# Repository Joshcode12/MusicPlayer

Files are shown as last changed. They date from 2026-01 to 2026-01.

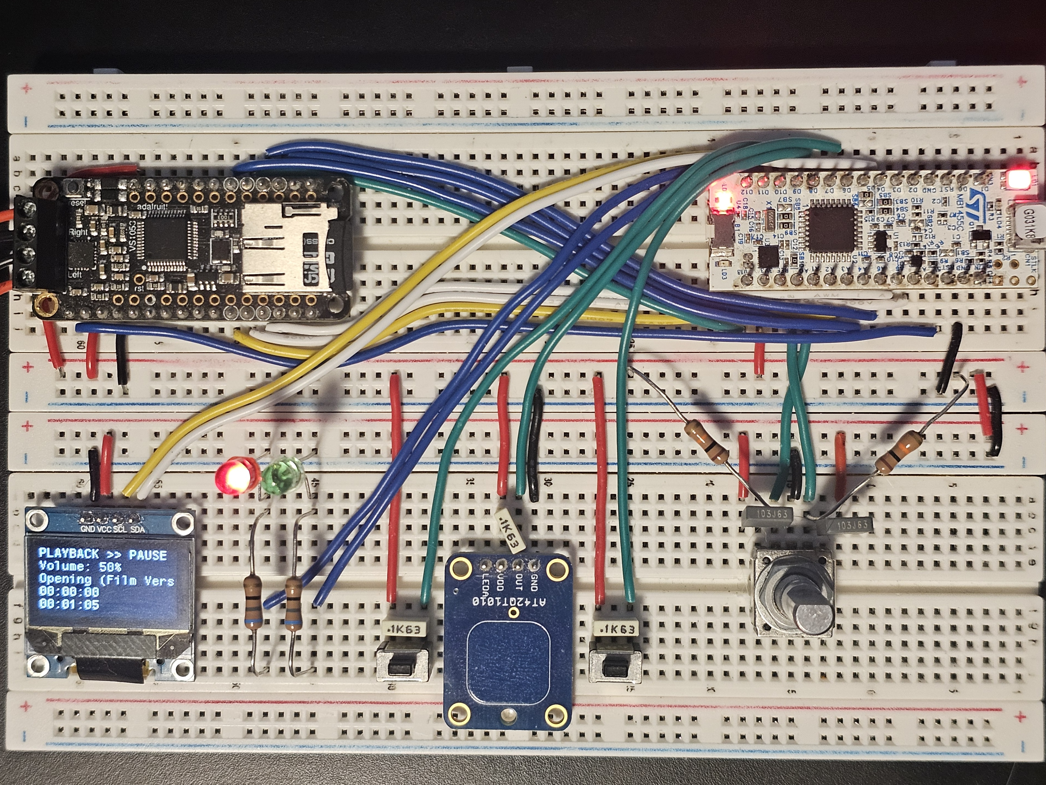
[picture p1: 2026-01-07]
Extra/Breadboard.jpg

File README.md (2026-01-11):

* * * * *

STM32 Music Player
==================




A standalone MP3 player built around the STM32G031K8 microcontroller, featuring SD card storage, OLED display, rotary encoder control, and a VS1053b hardware audio decoder. Designed to run on extremely limited Flash/RAM while remaining responsive and fully non‐blocking.

* * * * *

**Current Version:** v1.0.0 (First Release)

Hardware Components
-------------------

- **MCU**: STM32G031K8 (NUCLEO‐G031K8 board)
- **Audio Decoder**: VS1053b (MP3/AAC/WMA/MIDI hardware decoder)
- **Display**: SSD1306 128×64 OLED (I²C)
- **Storage**: SD Card (SPI, 3‑wire mode)
- **Controls**:
    - Rotary encoder (navigation + volume)
    - 3 push buttons (Play, Next, Previous)
    - Hardware debouncing via RC filters
- **Indicators**:
    - 2 PWM‑controlled LEDs (Play/Pause status)

* * * * *

Features
--------
- MP3 playback via VS1053b
- SD card access using lightweight SPI driver
- OLED UI with playback state and metadata
- Rotary encoder for navigation and volume
- Play / Pause / Next / Previous buttons
- Non‐blocking state machine
- Automatic ID3 tag extraction (title, duration)
- Simple numeric track system (`001.mp3`, `002.mp3`, ...)

* * * * *

SD Card Layout
--------------

Playback is intentionally **non‐recursive** for speed and RAM efficiency.

```
/audio/
    001.mp3
    002.mp3
    003.mp3
```

* * * * *

Pin Configuration
-----------------

### SPI1 --- Audio & SD Card
- PA5 --- SPI1_SCK
- PA6 --- SPI1_MISO
- PA7 --- SPI1_MOSI
- PA4 --- SD_CS
- PA11 --- MP3_CS
- PA12 --- XD_CS
- PB3 --- DREQ (VS1053b Data Request)

### I2C1 --- OLED Display
- PA9 --- I2C1_SCL (400 kHz)
- PA10 --- I2C1_SDA

### TIM2 --- Rotary Encoder
- PA0 --- TIM2_CH1
- PA1 --- TIM2_CH2

### TIM3 --- PWM LEDs
- PB4 --- TIM3_CH1 (Pause LED)
- PB5 --- TIM3_CH2 (Play LED)

### Buttons
- PB0 --- Play/Pause
- PB8 --- Next
- PB9 --- Previous

### Other
- PC6 --- LD3 (Status LED)

* * * * *

Software Architecture
---------------------

### Initialization Order
1. `HAL_Init()`
2. `SystemClock_Config()` --- 64 MHz (HSI + PLL)
3. `MX_GPIO_Init()` --- all CS pins HIGH
4. `MX_DMA_Init()`
5. `MX_SPI1_Init()` --- 2 Mbps
6. `MX_I2C1_Init()` --- 400 kHz
7. `MX_TIM2_Init()` --- encoder mode
8. `MX_TIM3_Init()` --- PWM LEDs
9. `MX_FATFS_Init()` --- filesystem

### DMA Channels
- DMA1_CH4 --- I2C1_TX

### Libraries
- **HAL** --- STM32 HAL
- **FatFS** --- R0.12c
- **SD Card SPI driver** --- kiwih/cubeide-sd-card
- **SSD1306 OLED** --- afiskon/stm32-ssd1306

* * * * *

Playback Architecture
---------------------

### Event Queue
- Lock‐free SPSC ring buffer
- Used for button and encoder events
- Extremely lightweight (8‑entry queue)

### State Machine
- **Playback State**
- **Error State**
- Fully non‐blocking (no `HAL_Delay()` inside states except when needed to show user info before it is updated)

### ID3 Tag Extraction
- Reads ID3v2 tags when loading a track
- Extracts:
    - Title
    - Duration
- Requires only a small buffer of 64 bytes

### File Naming
- Firmware generates filenames:
  ```
  audio/%03d.mp3
  ```
- No directory scanning required, but was done to avoid wrapping around
- Perfect for low‑RAM systems

* * * * *

Development Phases
------------------

### Phase 1 --- Hardware Bring‐Up
- [x] GPIO + PWM LED test
- [x] Button input
- [x] Rotary encoder reading

### Phase 2 --- Peripherals
- [x] SSD1306 display
- [x] SD card SPI driver
- [x] FatFS mounting

### Phase 3 --- Audio
- [X] VS1053b SPI communication
- [X] MP3 streaming from SD card

### Phase 4 --- Integration
- [X] Playback controls
- [X] Volume control via encoder
- [X] Track metadata display (Title and duration)
- [X] Volume storage

* * * * *

Building and Flashing
---------------------

### Build (CMake)

```
mkdir build && cd build
cmake ..
make
```

### Flash (st-flash)

```
st-flash write build/MusicPlayerFirmware.bin 0x8000000
```

### Flash (STM32CubeProgrammer)

Use ST‑Link to flash the `.elf` file.

* * * * *

Pictures
--------
Breadboard image

Cubemx pin-out

License
-------

MIT

Author
------

Joshua E

Acknowledgments
---------------
-   STMicroelectronics --- HAL/LL drivers
-   VLSI Solution --- VS1053b documentation
-   Aleksander Alekseev --- SSD1306 library
-   Hammond Pearce --- SD card SPI driver

* * * * *

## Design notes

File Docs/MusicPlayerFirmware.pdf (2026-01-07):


07/01/2026

MusicPlayerFirmware Project Configuration Report

## 1. Description

### 1.1. Project

Project Name | MusicPlayerFirmware
Board Name | NUCLEO-G031K8
Generated with: | STM32CubeMX 6.16.1
Date | 01/07/2026

### 1.2. MCU

MCU Series | STM32G0
MCU Line | STM32G0x1
MCU name | STM32G031K8Tx
MCU Package | LQFP32
MCU Pin number | 32

### 1.3. Core(s) information

Core(s) | ARM Cortex-M0+

## 2. Pinout Configuration

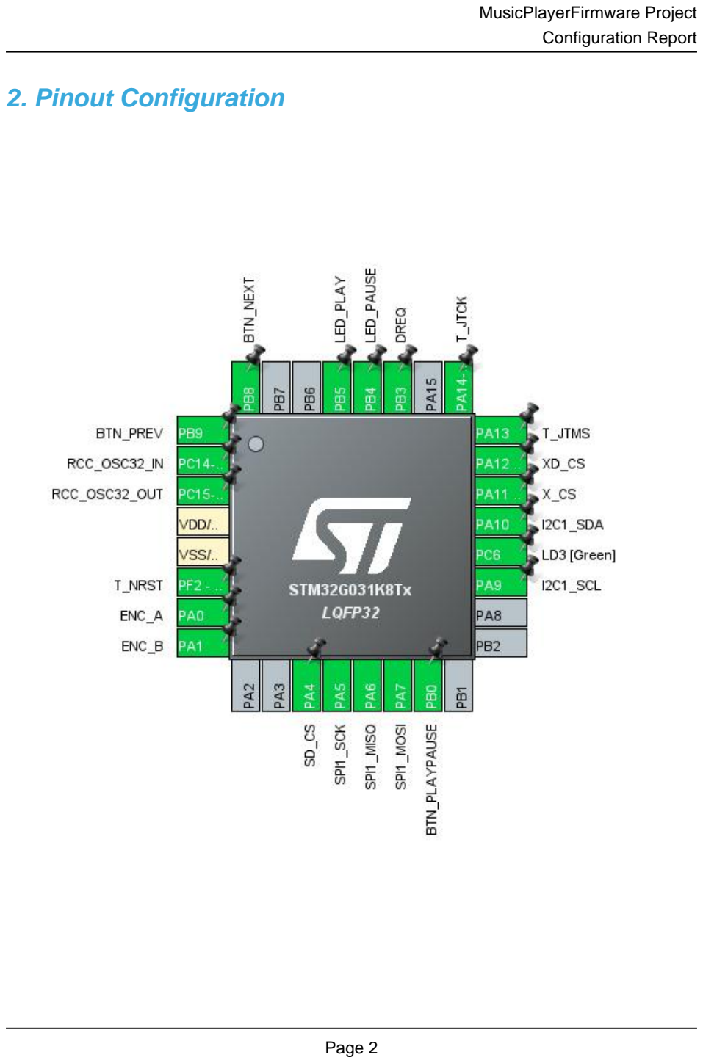
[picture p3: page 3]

## 3. Pins Configuration

Pin Number LQFP32 | Pin Name (function after reset) | Pin Type | Alternate Function(s) | Label
1 | PB9 | I/O | GPIO_EXTI9 | BTN_PREV
2 | PC14-OSC32_IN (PC14) | I/O | RCC_OSC32_IN
3 | PC15-OSC32_OUT (PC15) | I/O | RCC_OSC32_OUT
4 | VDD/VDDA | Power
5 | VSS/VSSA | Power
6 | PF2 - NRST | I/O | GPIO_EXTI2 | T_NRST
7 | PA0 | I/O | TIM2_CH1 | ENC_A
8 | PA1 | I/O | TIM2_CH2 | ENC_B
11 | PA4 * | I/O | GPIO_Output | SD_CS
12 | PA5 | I/O | SPI1_SCK | SPI1_SCK
13 | PA6 | I/O | SPI1_MISO | SPI1_MISO
14 | PA7 | I/O | SPI1_MOSI | SPI1_MOSI
15 | PB0 | I/O | GPIO_EXTI0 | BTN_PLAYPAUSE
19 | PA9 | I/O | I2C1_SCL
20 | PC6 * | I/O | GPIO_Output | LD3 [Green]
21 | PA10 | I/O | I2C1_SDA
22 | PA11 [PA9] * | I/O | GPIO_Output | X_CS
23 | PA12 [PA10] * | I/O | GPIO_Output | XD_CS
24 | PA13 | I/O | SYS_SWDIO | T_JTMS
25 | PA14-BOOT0 | I/O | SYS_SWCLK | T_JTCK
27 | PB3 * | I/O | GPIO_Input | DREQ
28 | PB4 | I/O | TIM3_CH1 | LED_PAUSE
29 | PB5 | I/O | TIM3_CH2 | LED_PLAY
32 | PB8 | I/O | GPIO_EXTI8 | BTN_NEXT

* The pin is affected with an I/O function

## 4. Clock Tree Configuration

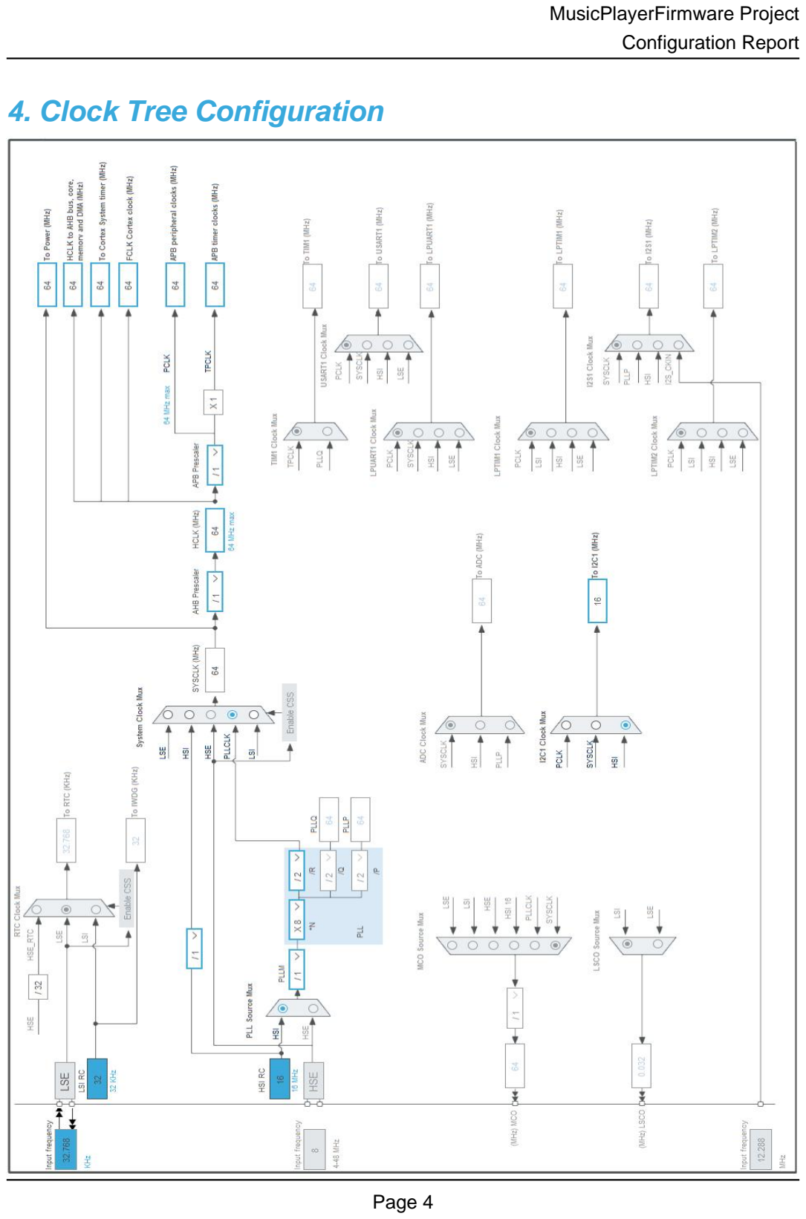
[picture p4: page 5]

## 1. Power Consumption Calculator report

### 1.1. Microcontroller Selection

Series | STM32G0
Line | STM32G0x1
MCU | STM32G031K8Tx
Datasheet | DS12992_Rev0

### 1.2. Parameter Selection

Temperature | 25
Vdd | 3.0

### 1.3. Battery Selection

Battery | Li-SOCL2(AAA700)
Capacity | 700.0 mAh
Self Discharge | 0.08 %/month
Nominal Voltage | 3.6 V
Max Cont Current | 10.0 mA
Max Pulse Current | 30.0 mA
Cells in series | 1
Cells in parallel | 1

### 1.4. Sequence

Step | Step1 | Step2
Mode | RUN | STOP1
Vdd | 3.0 | 3.0
Voltage Source | Battery | Battery
Range | Range1-High | Range1-High
Fetch Type | FLASH | Flash-PowerDown
CPU Frequency | 64 MHz | 16 MHz
Clock Configuration | HSI PLL | HSI
Clock Source Frequency | 16 MHz | 16 MHz
Peripherals
Additional Cons. | 0 mA | 0 mA
Average Current | 5.25 mA | 3.36 µA
Duration | 0.1 ms | 0.9 ms
DMIPS | 80.0 | 0.0
Ta Max | 128.8 | 130
Category | In DS Table | In DS Table

### 1.5. Results

Sequence Time | 1 ms | Average Current | 528.02 µA
Battery Life | 1 month, 24 days, 17 hours | Average DMIPS | 80.0 DMIPS

### 1.6. Chart

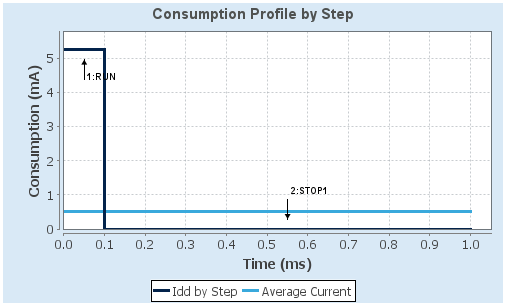
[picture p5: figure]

## 2. Software Project

### 2.1. Project Settings

Name | Value
Project Name | MusicPlayerFirmware
Project Folder | C:\Users\joshs\PersonalProjects\EmbeddedProjects\MusicPlayer\MusicPlayerFir
Toolchain / IDE | CMake
Firmware Package Name and Version | STM32Cube FW_G0 V1.6.2
Application Structure | Advanced
Generate Under Root | No
Do not generate the main() | No
Minimum Heap Size | 0x200
Minimum Stack Size | 0x400

### 2.2. Code Generation Settings

Name | Value
STM32Cube MCU packages and embedded software | Copy only the necessary library files
Generate peripheral initialization as a pair of '.c/.h' files | Yes
Backup previously generated files when re-generating | No
Keep User Code when re-generating | Yes
Delete previously generated files when not re-generated | Yes
Set all free pins as analog (to optimize the power consumption) | Yes
Enable Full Assert | No

### 2.3. Advanced Settings - Generated Function Calls

Rank | Function Name | Peripheral Instance Name
1 | SystemClock_Config | RCC
2 | MX_GPIO_Init | GPIO
3 | MX_DMA_Init | DMA
4 | MX_I2C1_Init | I2C1
5 | MX_SPI1_Init | SPI1
6 | MX_TIM3_Init | TIM3
7 | MX_TIM2_Init | TIM2
8 | MX_FATFS_Init | FATFS

## 3. Peripherals and Middlewares Configuration

### 3.1. I2C1

I2C: I2C
3.1.1. Parameter Settings:

Timing configuration:

Custom Timing | Disabled
I2C Speed Mode | Fast Mode *
I2C Speed Frequency (KHz) | 400
Rise Time (ns) | 100
Fall Time (ns) | 100
Coefficient of Digital Filter | 0
Analog Filter | Enabled
Timing | 0x00300617 *
Slave Features:
Clock No Stretch Mode | Disabled
General Call Address Detection | Disabled
Primary Address Length selection | 7-bit
Dual Address Acknowledged | Disabled
Primary slave address | 60 *

### 3.2. RCC

Low Speed Clock (LSE) : Crystal/Ceramic Resonator
3.2.1. Parameter Settings:

System Parameters:

VDD voltage (V) | 3.3
Instruction Cache | Enabled
Prefetch Buffer | Enabled
Data Cache | Enabled
Flash Latency(WS) | 2 WS (3 CPU cycle)
RCC Parameters:
HSI Calibration Value | 64
HSE Startup Timout Value (ms) | 100
LSE Startup Timout Value (ms) | 5000
Power Parameters:
Power Regulator Voltage Scale | Power Regulator Voltage Scale 1

Peripherals Clock Configuration:

Generate the peripherals clock configuration | TRUE

### 3.3. SPI1

Mode: Full-Duplex Master
3.3.1. Parameter Settings:

Basic Parameters:

Frame Format | Motorola
Data Size | 8 Bits
First Bit | MSB First
Clock Parameters:
Prescaler (for Baud Rate) | 8 *
Baud Rate | 8.0 MBits/s *
Clock Polarity (CPOL) | Low
Clock Phase (CPHA) | 1 Edge
Advanced Parameters:
CRC Calculation | Disabled
NSSP Mode | Enabled
NSS Signal Type | Software

### 3.4. SYS

mode: Debug
Timebase Source: SysTick

### 3.5. TIM2

Combined Channels: Encoder Mode
3.5.1. Parameter Settings:

Counter Settings:

Prescaler (PSC - 16 bits value) | 0
Counter Mode | Up
Counter Period (AutoReload Register - 32 bits value ) | 4294967295
Internal Clock Division (CKD) | No Division
auto-reload preload | Disable
Trigger Output (TRGO) Parameters:

Master/Slave Mode (MSM bit) | Disable (Trigger input effect not delayed)
Trigger Event Selection TRGO | Reset (UG bit from TIMx_EGR)
Encoder:
Encoder Mode | Encoder Mode TI1 and TI2 *

____ Parameters for Channel 1 ____
Polarity | Falling Edge *
IC Selection | Direct
Prescaler Division Ratio | No division
Input Filter | 0
____ Parameters for Channel 2 ____
Polarity | Falling Edge *
IC Selection | Direct
Prescaler Division Ratio | No division
Input Filter | 0

### 3.6. TIM3

Channel1: PWM Generation CH1 Channel2: PWM Generation CH2
3.6.1. Parameter Settings:

Counter Settings:

Prescaler (PSC - 16 bits value) | 63 *
Counter Mode | Up
Counter Period (AutoReload Register - 16 bits value ) | 999 *
Internal Clock Division (CKD) | No Division
auto-reload preload | Enable *
Trigger Output (TRGO) Parameters:
Master/Slave Mode (MSM bit) | Disable (Trigger input effect not delayed)
Trigger Event Selection TRGO | Reset (UG bit from TIMx_EGR)
Clear Input:
Clear Input Source | Disable
PWM Generation Channel 1:
Mode | PWM mode 1
Pulse (16 bits value) | 250 *
Output compare preload | Enable
Fast Mode | Disable
CH Polarity | High
PWM Generation Channel 2:

Mode | PWM mode 1
Pulse (16 bits value) | 250 *
Output compare preload | Enable
Fast Mode | Disable
CH Polarity | High

### 3.7. FATFS

mode: User-defined
3.7.1. Set Defines:

Version:

FATFS version | R0.12c
Function Parameters:
FS_READONLY (Read-only mode) | Disabled
FS_MINIMIZE (Minimization level) | Enabled with 6 functions removed *
USE_STRFUNC (String functions) | Disabled *
USE_FIND (Find functions) | Disabled
USE_MKFS (Make filesystem function) | Disabled *
USE_FASTSEEK (Fast seek function) | Disabled *
USE_EXPAND (Use f_expand function) | Disabled
USE_CHMOD (Change attributes function) | Disabled
USE_LABEL (Volume label functions) | Disabled
USE_FORWARD (Forward function) | Disabled
Locale and Namespace Parameters:
CODE_PAGE (Code page on target) | Latin 1
USE_LFN (Use Long Filename) | Disabled
MAX_LFN (Max Long Filename) | 255
LFN_UNICODE (Enable Unicode) | ANSI/OEM
STRF_ENCODE (Character encoding) | ANSI/OEM *
FS_RPATH (Relative Path) | Disabled
Physical Drive Parameters:
VOLUMES (Logical drives) | 1
MAX_SS (Maximum Sector Size) | 512
MIN_SS (Minimum Sector Size) | 512
MULTI_PARTITION (Volume partitions feature) | Disabled
USE_TRIM (Erase feature) | Disabled
FS_NOFSINFO (Force full FAT scan) | 0
System Parameters:

FS_TINY (Tiny mode)

| Enabled *
FS_EXFAT (Support of exFAT file system) | Disabled
FS_NORTC (Timestamp feature) | Fixed timestamp *
NORTC_YEAR (Year for timestamp) | 2026 *
NORTC_MON (Month for timestamp) | 1 *
NORTC_MDAY (Day for timestamp) | 1 *
FS_REENTRANT (Re-Entrancy) | Disabled
FS_TIMEOUT (Timeout ticks) | 1000
FS_LOCK (Number of files opened simultaneously) | 1 *

* User modified value

## 4. System Configuration

### 4.1. GPIO configuration

IP | Pin | Signal | GPIO mode | GPIO pull/up pull down | Max Speed | User Label
I2C1 | PA9 | I2C1_SCL | Alternate Function Open Drain | Pull-up * | Low
| PA10 | I2C1_SDA | Alternate Function Open Drain | Pull-up * | Low
RCC | PC14-OSC32_IN (PC14) | RCC_OSC32_IN | n/a | n/a | n/a
| PC15-OSC32_OU T (PC15) | RCC_OSC32_O UT | n/a | n/a | n/a
SPI1 | PA5 | SPI1_SCK | Alternate Function Push Pull | No pull-up and no pull-down | Low | SPI1_SCK
| PA6 | SPI1_MISO | Alternate Function Push Pull | Pull-up * | Low | SPI1_MISO
| PA7 | SPI1_MOSI | Alternate Function Push Pull | Pull-up * | Low | SPI1_MOSI
SYS | PA13 | SYS_SWDIO | n/a | n/a | n/a | T_JTMS
| PA14-BOOT0 | SYS_SWCLK | n/a | n/a | n/a | T_JTCK
TIM2 | PA0 | TIM2_CH1 | Alternate Function Push Pull | No pull-up and no pull-down | Low | ENC_A
| PA1 | TIM2_CH2 | Alternate Function Push Pull | No pull-up and no pull-down | Low | ENC_B
TIM3 | PB4 | TIM3_CH1 | Alternate Function Push Pull | No pull-up and no pull-down | Low | LED_PAUSE
| PB5 | TIM3_CH2 | Alternate Function Push Pull | No pull-up and no pull-down | Low | LED_PLAY
GPIO | PB9 | GPIO_EXTI9 | External Interrupt Mode with Rising edge trigger detection | Pull-down * | n/a | BTN_PREV
| PF2 - NRST | GPIO_EXTI2 | External Interrupt Mode with Rising edge trigger detection | No pull-up and no pull-down | n/a | T_NRST
| PA4 | GPIO_Output | Output Push Pull | Pull-up * | Low | SD_CS
| PB0 | GPIO_EXTI0 | External Interrupt Mode with Rising edge trigger detection | Pull-down * | n/a | BTN_PLAYPAUSE
| PC6 | GPIO_Output | Output Push Pull | No pull-up and no pull-down | Low | LD3 [Green]
| PA11 [PA9] | GPIO_Output | Output Push Pull | Pull-up * | Low | X_CS
| PA12 [PA10] | GPIO_Output | Output Push Pull | Pull-up * | Low | XD_CS
| PB3 | GPIO_Input | Input mode | Pull-down * | n/a | DREQ
| PB8 | GPIO_EXTI8 | External Interrupt Mode with Rising edge trigger detection | Pull-down * | n/a | BTN_NEXT

### 4.2. DMA configuration

DMA request | Stream | Direction | Priority
I2C1_TX | DMA1_Channel1 | Memory To Peripheral | Medium *

I2C1_TX: DMA1_Channel1 DMA request Settings:

Mode: | Normal
Peripheral Increment: | Disable
Memory Increment: | Enable *
Peripheral Data Width: | Byte
Memory Data Width: | Byte

### 4.3. NVIC configuration

4.3.1. NVIC
Interrupt Table | Enable | Preenmption Priority | SubPriority
Non maskable interrupt | true | 0 | 0
Hard fault interrupt | true | 0 | 0
System service call via SWI instruction | true | 0 | 0
Pendable request for system service | true | 0 | 0
System tick timer | true | 0 | 0
EXTI line 0 and line 1 interrupts | true | 0 | 0
EXTI line 2 and line 3 interrupts | true | 0 | 0
EXTI line 4 to 15 interrupts | true | 0 | 0
DMA1 channel 1 interrupt | true | 0 | 0
I2C1 event global interrupt / I2C1 wake-up interrupt through EXTI line 23 | true | 0 | 0
SPI1 global interrupt | true | 0 | 0
PVD interrupt through EXTI line 16 | unused
Flash global interrupt | unused
RCC global interrupt | unused
TIM2 global interrupt | unused
TIM3 global interrupt | unused
4.3.2. NVIC Code generation
Enabled interrupt Table | Select for init sequence ordering | Generate IRQ handler | Call HAL handler
Non maskable interrupt | false | true | false
Hard fault interrupt | false | true | false
System service call via SWI instruction | false | true | false
Pendable request for system service | false | true | false
System tick timer | false | true | true
EXTI line 0 and line 1 interrupts | false | true | true
EXTI line 2 and line 3 interrupts | false | true | true
EXTI line 4 to 15 interrupts | false | true | true
DMA1 channel 1 interrupt | false | true | true
I2C1 event global interrupt / I2C1 wake-up interrupt through EXTI line 23 | false | true | true
SPI1 global interrupt | false | true | true

* User modified value

## 5. System Views

5.1. Category view
5.1.1. Current

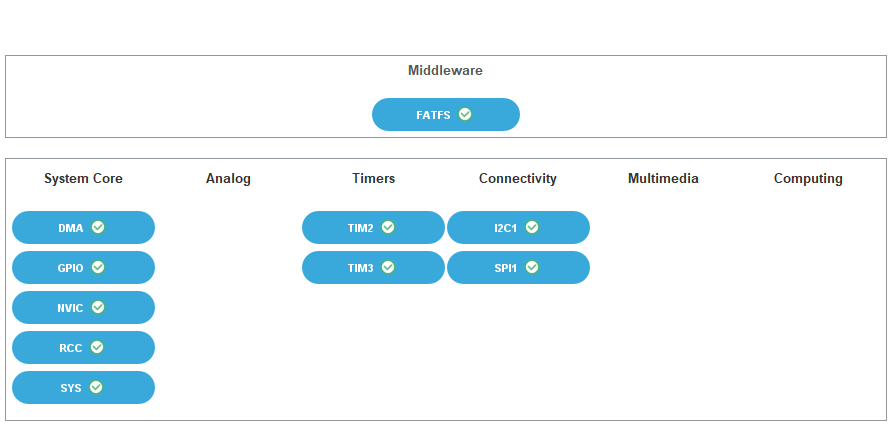
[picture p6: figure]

## 6. Docs & Resources

Type | Link
IBIS models | https://www.st.com/resource/en/ibis_model/stm32g0_ibis.zip
System View Description | https://www.st.com/resource/en/svd/stm32g0-svd.zip
Presentations | https://www.st.com/resource/en/product_presentation/stm32-stm8_embedded_software_solutions.pdf
Presentations | https://www.st.com/resource/en/product_presentation/stm32_eval-tools_portfolio.pdf
Presentations | https://www.st.com/resource/en/product_presentation/stm32_stm8_functi onal-safety-packages.pdf
Presentations | https://www.st.com/resource/en/product_presentation/stm32g0_marketing_pres.pdf
Presentations | https://www.st.com/resource/en/product_presentation/stm32-usb-c-pd-solutions-presentation.pdf
Presentations | https://www.st.com/resource/en/product_presentation/stm32-stm8_software_development_tools.pdf
Presentations | https://www.st.com/resource/en/product_presentation/microcontrollers-stm32-family-overview.pdf
Presentations | https://www.st.com/resource/en/product_presentation/microcontrollers-stm32-entry-level-graphics.pdf
Brochures | https://www.st.com/resource/en/brochure/products-and-solutions-for-plcs-and-smart-i-os.pdf
Brochures | https://www.st.com/resource/en/brochure/expansion-boards-for-intelligent-power-switches.pdf
Flyers | https://www.st.com/resource/en/flyer/flstm32g0.pdf
Flyers | https://www.st.com/resource/en/flyer/flstm32nucleo.pdf
Flyers | https://www.st.com/resource/en/flyer/flstm32trust.pdf
Flyers | https://www.st.com/resource/en/flyer/fldpstpfc11120.pdf
Security Bulletin | https://www.st.com/resource/en/technical_note/tn1489-security-bulletin- tn1489stpsirt-physical-attacks-on-stm32-and-stm32cube-firmware-

| stmicroelectronics.pdf
Application Notes | https://www.st.com/resource/en/application_note/an1709-emc-design-guide-for-stm8-stm32-and-legacy-mcus-stmicroelectronics.pdf
Application Notes | https://www.st.com/resource/en/application_note/an3126-audio-and-waveform-generation-using-the-dac-in-stm32-products-stmicroelectronics.pdf
Application Notes | https://www.st.com/resource/en/application_note/an3155-usart-protocol-used-in-the-stm32-bootloader-stmicroelectronics.pdf
Application Notes | https://www.st.com/resource/en/application_note/an3156-usb-dfu-protocol-used-in-the-stm32-bootloader-stmicroelectronics.pdf
Application Notes | https://www.st.com/resource/en/application_note/an4221-i2c-protocol-used-in-the-stm32-bootloader-stmicroelectronics.pdf
Application Notes | https://www.st.com/resource/en/application_note/an4286-spi-protocol-used-in-the-stm32-bootloader-stmicroelectronics.pdf
Application Notes | https://www.st.com/resource/en/application_note/an4655-virtually-increasing-the-number-of-serial-communication-peripherals-in-stm32-applications-stmicroelectronics.p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
Application Notes | https://www.st.com/resource/en/application_note/an4750-handling-of-soft-errors-in-stm32-applications-stmicroelectronics.pdf
Application Notes | https://www.st.com/resource/en/application_note/an4776-generalpurpose-timer-cookbook-for-stm32-microcontrollers-stmicroelectronics.pdf
Application Notes | https://www.st.com/resource/en/application_note/an4803-highspeed-si-simulations-using-ibis-and-boardlevel-simulations-using-hyperlynx-si-on-stm32-mcus-and-mpus-stmic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
Application Notes | https://www.st.com/resource/en/application_note/an4989-stm32-microcontroller-debug-toolbox-stmicroelectronics.pdf
Application Notes | https://www.st.com/resource/en/application_note/an5027-interfacing-pdm-digital-microphones-using-stm32-mcus-and-mpus-stmicroelectronics.pdf
Application Notes | https://www.st.com/resource/en/application_note/an5096-getting-started-with-stm32g0-series-hardware-development-stmicroelectronics.pdf
Application Notes | https://www.st.com/resource/en/application_note/an5110-stm32cube-firmware-examples-for-stm32g0-series-stmicroelectronics.pdf
Application Notes | https://www.st.com/resource/en/application_note/an5145-migration-of-

| applications-from-stm32f0-series-to-stm32g0-series--stmicroelectronics.pdf
Application Notes | https://www.st.com/resource/en/application_note/an4899-stm32-microcontroller-gpio-hardware-settings-and-lowpower-consumption-stmicroelectronics.pdf
Application Notes | https://www.st.com/resource/en/application_note/an5612-esd-protection-of-stm32-mcus-and-mpus-stmicroelectronics.pdf
Application Notes | https://www.st.com/resource/en/application_note/an4991-how-to-wake-up-an-stm32-microcontroller-from-lowpower-mode-with-the-usart-or-the-lpuart-stmicroelectronics.pdf
Application Notes | https://www.st.com/resource/en/application_note/an4838-introduction-to-memory-protection-unit-management-on-stm32-mcus-stmicroelectronics.pdf
Application Notes | https://www.st.com/resource/en/application_note/an5225-introduction-to-usb-typec-power-delivery-for-stm32-mcus-and-mpus-stmicroelectronics.pdf
Application Notes | https://www.st.com/resource/en/application_note/an4777-how-to-optimize-power-consumption-on-stm32-mcus-stmicroelectronics.pdf
Application Notes | https://www.st.com/resource/en/application_note/an4894-how-to-use-eeprom-emulation-on-stm32-mcus-stmicroelectronics.pdf
Application Notes | https://www.st.com/resource/en/application_note/an5537-how-to-use-adc-oversampling-techniques-to-improve-signaltonoise-ratio-on-stm32-mcus-stmicroelectronics.pdf
Application Notes | https://www.st.com/resource/en/application_note/an5036-guidelines-for-thermal-management-on-stm32-applications-stmicroelectronics.pdf
Application Notes | https://www.st.com/resource/en/application_note/an5405-how-to-use-fdcan-bootloader-protocol-on-stm32-mcus-stmicroelectronics.pdf
Application Notes | https://www.st.com/resource/en/application_note/an5690-how-to-use-vrefbuf-peripheral-on-stm32-mcus-and-mpus-stmicroelectronics.pdf
Application Notes | https://www.st.com/resource/en/application_note/an4230-introduction-to-random-number-generation-validation-using-the-nist-statistical-test-suite-for-stm32-mcus-and-m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
Application Notes | https://www.st.com/resource/en/application_note/an2548-introduction-to-

| dma-controller-for-stm32-mcus-stmicroelectronics.pdf
Application Notes | https://www.st.com/resource/en/application_note/an4013-introduction-to-timers-for-stm32-mcus-stmicroelectronics.pdf
Application Notes | https://www.st.com/resource/en/application_note/an4277-how-to-use-pwm-shutdown-for-motor-control-and-digital-power-conversion-on-stm32-mcus-stmicroelectronics.pdf
Application Notes | https://www.st.com/resource/en/application_note/an4635-how-to-optimize-lpuart-power-consumption-on-stm32-mcus-stmicroelectronics.pdf
Application Notes | https://www.st.com/resource/en/application_note/an4759-introduction-to-using-the-hardware-realtime-clock-rtc-and-the-tamper-management-unit-tamp-with-stm32-mcus-stmi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
Application Notes | https://www.st.com/resource/en/application_note/an4908-getting-started-with-usart-automatic-baud-rater-detection-for-stm32-mcus-stmicroelectronics.pdf
Application Notes | https://www.st.com/resource/en/application_note/an5156-introduction-to-security-for-stm32-mcus-stmicroelectronics.pdf
Application Notes | https://www.st.com/resource/en/application_note/an5224-introduction-to-dmamux-for-stm32-mcus-stmicroelectronics.pdf
Application Notes | https://www.st.com/resource/en/application_note/an5543-guidelines-for-enhanced-spi-communication-on-stm32-mcus-and-mpus-stmicroelectronics.pdf
Application Notes | https://www.st.com/resource/en/application_note/an5348-introduction-to-fdcan-peripherals-for-stm32-mcus-stmicroelectronics.pdf
Application Notes | https://www.st.com/resource/en/application_note/an5969-migrating-between-stm32g0-and-stm32c0-mcus-stmicroelectronics.pdf
Application Notes | https://www.st.com/resource/en/application_note/cd00211314-how-to-optimize-the-adc-accuracy-in-the-stm32-mcus-stmicroelectronics.pdf
Application Notes | https://www.st.com/resource/en/application_note/an2639-soldering-recommendations-and-package-information-for-leadfree-ecopack2-mcus-and-mpus-stmicroelectronics.pdf
Application Notes | https://www.st.com/resource/en/application_note/an6226-migrating-between-stm32g0-and-stm32u0-mcus-stmicroelectronics.pdf

Application Notes | https://www.st.com/resource/en/application_note/an4566-how-to-extend-the-dac-performance-on-stm32-mcus-stmicroelectronics.pdf
Application Notes | https://www.st.com/resource/en/application_note/an5647-the-goertzel-algorithm-to-compute-individual-terms-of-the-discrete-fourier-transform-dft-in-stm32-products-stm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
Application Notes | https://www.st.com/resource/en/application_note/an2606-introduction-to-system-memory-boot-mode-on-stm32-mcus-stmicroelectronics.pdf
Application Notes for related Tools & Software | https://www.st.com/resource/en/application_note/an4657-stm32-inapplication-programming-iap-using-the-usart-stmicroelectronics.pdf
Application Notes for related Tools & Software | https://www.st.com/resource/en/application_note/an4841-digital-signal-processing-for-stm32-microcontrollers-using-cmsis-stmicroelectronics.pdf
Application Notes for related Tools & Software | https://www.st.com/resource/en/application_note/an5056-integration-guide-for-the-xcubesbsfu-stm32cube-expansion-package-stmicroelectronics.pdf
Application Notes for related Tools & Software | https://www.st.com/resource/en/application_note/an5110-stm32cube-firmware-examples-for-stm32g0-series-stmicroelectronics.pdf
Application Notes for related Tools & Software | https://www.st.com/resource/en/application_note/an5360-getting-started-with-projects-based-on-the-stm32mp1-series-in-stm32cubeide-stmicroelectronics.pdf
Application Notes for related Tools & Software | https://www.st.com/resource/en/application_note/an5361-getting-started-with-projects-based-on-dualcore-stm32h7-microcontrollers-in-stm32cubeide-stmicroelectronics.pd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
Application Notes for related Tools & Software | https://www.st.com/resource/en/application_note/an5394-getting-started-with-projects-based-on-the-stm32l5-series-in-stm32cubeide-stmicroelectronics.pdf
Application Notes for related Tools & Software | https://www.st.com/resource/en/application_note/an5418-how-to-build-a-simple-usbpd-sink-application-with-stm32cubemx-stmicroelectronics.pdf
Application Notes for related Tools & Software | https://www.st.com/resource/en/application_note/an5426-migrating-graphics-middleware-projects-from-stm32cubemx-540-to-stm32cubemx-550-stmicroelectronics.pdf

Application Notes for related Tools & Software | https://www.st.com/resource/en/application_note/an5564-getting-started-with-projects-based-on-dualcore-stm32wl-microcontrollers-in-stm32cubeide-stmicroelectronics.pd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
Application Notes for related Tools & Software | https://www.st.com/resource/en/application_note/an4865-lowpower-timer-lptim-applicative-use-cases-on-stm32-mcus-and-mpus-stmicroelectronics.pdf
Application Notes for related Tools & Software | https://www.st.com/resource/en/application_note/an5698-adapting-the-xcubestl-functional-safety-package-for-stm32-iec-61508-compliant-to-other-safety-standards-stmicr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
Application Notes for related Tools & Software | https://www.st.com/resource/en/application_note/an5731-stm32cubemx-and-stm32cubeide-threadsafe-solution-stmicroelectronics.pdf
Application Notes for related Tools & Software | https://www.st.com/resource/en/application_note/an4502-stm32-smbuspmbus-expansion-package-for-stm32cube-stmicroelectronics.pdf
Application Notes for related Tools & Software | https://www.st.com/resource/en/application_note/an5952-how-to-use-cmake-in-stm32cubeide-stmicroelectronics.pdf
Application Notes for related Tools & Software | https://www.st.com/resource/en/application_note/an5054-how-to-perform-secure-programming-using-stm32cubeprogrammer-stmicroelectronics.pdf
Application Notes for related Tools & Software | https://www.st.com/resource/en/application_note/an6179-how-to-integrate-the-stl-firmware-into-a-time-critical-user-application-stmicroelectronics.pdf
Application Notes for related Tools & Software | https://www.st.com/resource/en/application_note/an6127-getting-started-with-stm32h7rx7sx-mcus-in-stm32cubeide-stmicroelectronics.pdf
Application Notes for related Tools & Software | https://www.st.com/resource/en/application_note/an6265-getting-started-with-stm32n6-mcus-in-stm32cubeide-stmicroelectronics.pdf
Errata Sheets | https://www.st.com/resource/en/errata_sheet/es0487-stm32g031x4x6x8-device-errata-stmicroelectronics.pdf
Datasheet | https://www.st.com/resource/en/datasheet/dm00613879.pdf
Programming | https://www.st.com/resource/en/programming_manual/pm0223-stm32-

Manuals | cortexm0-mcus-programming-manual-stmicroelectronics.pdf
Reference Manuals | https://www.st.com/resource/en/reference_manual/rm0444-stm32g0x1-advanced-armbased-32bit-mcus-stmicroelectronics.pdf
Technical Notes & Articles | https://www.st.com/resource/en/technical_note/tn1163-description-of-wlcsp-for-microcontrollers-and-recommendations-for-its-use-stmicroelectronics.pdf
Technical Notes & Articles | https://www.st.com/resource/en/technical_note/tn1204-tape-and-reel-shipping-media-for-stm32-microcontrollers-in-bga-packages-stmicroelectronics.pdf
Technical Notes & Articles | https://www.st.com/resource/en/technical_note/tn1205-tape-and-reel-shipping-media-for-stm8-and-stm32-microcontrollers-in-fpn-packages-stmicroelectronics.pdf
Technical Notes & Articles | https://www.st.com/resource/en/technical_note/tn1206-tape-and-reel-shipping-media-for-stm8-and-stm32-microcontrollers-in-qfp-packages-stmicroelectronics.pdf
Technical Notes & Articles | https://www.st.com/resource/en/technical_note/tn1207-tape-and-reel-shipping-media-for-stm8-and-stm32-microcontrollers-in-so-packages-stmicroelectronics.pdf
Technical Notes & Articles | https://www.st.com/resource/en/technical_note/tn1208-tape-and-reel-shipping-media-for-stm8-and-stm32-microcontrollers-in-tssop-and-ssop-packages-stmicroelectronics.p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
Technical Notes & Articles | https://www.st.com/resource/en/technical_note/tn1433-reference-device-marking-schematics-for-stm32-microcontrollers-and-microprocessors-stmicroelectronics.pdf
User Manuals | https://www.st.com/resource/en/user_manual/um3083-stm32g0-series-iec-60730-selftest-library-user-guide-stmicroelectronics.pdf

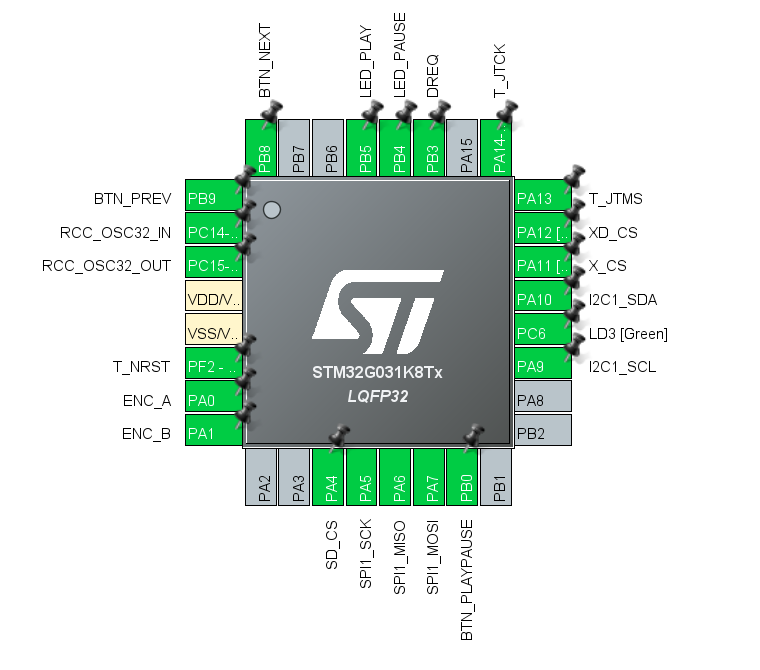
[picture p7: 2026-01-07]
Extra/CubemxPin-out.png

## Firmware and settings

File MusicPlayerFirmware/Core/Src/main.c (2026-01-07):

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
/* Includes ------------------------------------------------------------------*/
#include "main.h"
#include "dma.h"
#include "app_fatfs.h"
#include "i2c.h"
#include "spi.h"
#include "tim.h"
#include "gpio.h"

/* USER CODE BEGIN Includes */
#include <stdbool.h>
#include <string.h>
#include "ssd1306.h"
#include "ssd1306_fonts.h"
#include "vs1053.h"
#include "store.h"
/* USER CODE END Includes */

/* USER CODE BEGIN PTD */
typedef enum Event {
    EVENT_NONE,
    EVENT_NEXT,
    EVENT_PREV
} Event_t;

typedef struct EventQueue {
    volatile uint8_t head;
    volatile uint8_t tail;
    Event_t buffer[EVENT_QUEUE_SIZE];
} EventQueue_t;

typedef struct State {
    void (*init)(void);
    void (*run)(Event_t event);
} State_t;

typedef struct Encoder {
    TIM_HandleTypeDef* htim;
    int32_t last_counter;
    int32_t accum;
    int8_t steps;
} Encoder_t;

typedef enum ErrorType {
    ERROR_NONE,
    ERROR_DISK,
    ERROR_RESET
} ErrorType_t;

typedef enum DisplayMode {
    DISPLAY_MODE_PLAYBACK,
    DISPLAY_MODE_ERROR
} DisplayMode_t;

typedef struct MP3Info {
    char title[64];
    uint16_t duration;
} MP3Info_t;

typedef struct Flags {
    bool is_playing : 1;
    bool is_title : 1;
    bool is_tlen : 1;
} Flags_t;

/* USER CODE END PTD */

/* USER CODE BEGIN PD */
#define LED_PWM_TIM htim3
#define LED_PWM_SLOW 63999u
#define LED_PWM_FAST 63u
#define LED_PAUSE_CHANNEL TIM_CHANNEL_1
#define LED_PLAY_CHANNEL TIM_CHANNEL_2
#define COUNTS_PER_DETENT 4
#define SD_CHECK_INTERVAL 1000
#define DISPLAY_UPDATE_MS 250
#define LAST_VOLUME_UPDATE_MS 10000
/* USER CODE END PD */


/* USER CODE BEGIN PV */
/* Event Queue */
EventQueue_t event_queue = {0};

/* State */
const State_t STATE_PLAYBACK;
const State_t STATE_ERROR;

const State_t* current_state = &STATE_PLAYBACK;

/* Hardware */
Encoder_t encoder;
Flags_t flags = {0};
FATFS fatfs;
FIL file;

/* Audio */
uint16_t current_track = 1, max_tracks = 0;;
uint8_t volume = 0;
MP3Info_t mp3_info = {
    .title = "STARTUP...",
    .duration = 0
};

// MPEG-1 Layer III Bitrate Table (kbps)
static const uint16_t mpeg1_bitrates[15] =
    {0, 32, 40, 48, 56, 64, 80, 96, 112, 128, 160, 192, 224, 256, 320};

/* Error */
ErrorType_t current_error = ERROR_NONE;

/* USER CODE END PV */

void SystemClock_Config(void);
/* USER CODE BEGIN PFP */
/* Event queue */
void push_event(Event_t e);
Event_t pop_event(void);

/* State functions */
void change_state(const State_t* new_state);

void playback_init(void);
void playback_run(Event_t event);

void error_init(void);
void error_run(Event_t event);

/* Display */
void display_init(void);
void display_update(DisplayMode_t mode);

/* Rotary encoder */
void encoder_init(Encoder_t* enc, TIM_HandleTypeDef* htim);
void encoder_poll(Encoder_t* enc);

/* Audio */
uint8_t* track_path(void);
bool stream_chunk(void);
void open_file(void);
uint32_t read_be32(const uint8_t* p);
bool get_mp3_info(void);

/* SD card */
bool sdcard_init(void);
bool sdcard_recover(void);

/* USER CODE END PFP */

/* USER CODE BEGIN 0 */
const State_t STATE_PLAYBACK = {
    .init = playback_init,
    .run = playback_run,
};

const State_t STATE_ERROR = {
    .init = error_init,
    .run = error_run,
};

/* USER CODE END 0 */

/**
  * @brief  The application entry point.
  * @retval int
  */
int main(void) {
    /* MCU Configuration--------------------------------------------------------*/

    /* Reset of all peripherals, Initializes the Flash interface and the Systick. */
    HAL_Init();

    /* Configure the system clock */
    SystemClock_Config();

    /* Initialize all configured peripherals */
    MX_GPIO_Init();
    MX_DMA_Init();
    MX_I2C1_Init();
    MX_SPI1_Init();
    MX_TIM3_Init();
    MX_TIM2_Init();
    if (MX_FATFS_Init() != APP_OK) {
        Error_Handler();
    }
    /* USER CODE BEGIN 2 */
    encoder_init(&encoder, &htim2);
    display_init();

    if (!sdcard_init()) {
        current_error = ERROR_DISK;
        current_state = &STATE_ERROR;
    }

    if (!vs1053_init()) {
        current_error = ERROR_RESET;
        current_state = &STATE_ERROR;
    }

    if (!volume_load()) {
        volume = 50;
    }
    vs1053_set_volume(volume);

    display_update(DISPLAY_MODE_PLAYBACK);

    current_state->init();
    /* USER CODE END 2 */

    /* Infinite loop */
    /* USER CODE BEGIN WHILE */
    while (1) {
        // update the current encoder value
        encoder_poll(&encoder);
        static uint8_t last_saved_volume = 0;
        static uint32_t last_volume_change = 0;

        // use the encoder steps to a volume % in steps of 5
        if (encoder.steps != 0) {
            int16_t new_volume = (int16_t)(volume + encoder.steps * 5);

            if (new_volume < 0) new_volume = 0;
            if (new_volume > 100) new_volume = 100;

            volume = new_volume;
            encoder.steps = 0;
            vs1053_set_volume(volume);
            last_volume_change = HAL_GetTick();
        }

        // save after seconds to reduce flash where
        if (volume != last_saved_volume &&
            (HAL_GetTick() - last_volume_change) > LAST_VOLUME_UPDATE_MS) {
            if (volume_save()) {
                last_saved_volume = volume;
            }
        }

        // run the current state
        const Event_t event = pop_event();
        if (current_state->run) {
            current_state->run(event);
        }
        /* USER CODE END WHILE */

        /* USER CODE BEGIN 3 */
    }
    /* USER CODE END 3 */
}

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
/* USER CODE BEGIN 4 */
void HAL_GPIO_EXTI_Rising_Callback(uint16_t GPIO_Pin) {
    static uint32_t last_tick = 0;
    const uint32_t current_tick = HAL_GetTick();

    // had a very bouncy button
    if ((current_tick - last_tick) < 100)
        return;

    last_tick = current_tick;

    switch (GPIO_Pin) {
    case BTN_PLAYPAUSE_Pin:
        flags.is_playing ^= true;
        if (flags.is_playing) {
            HAL_TIM_PWM_Stop(&LED_PWM_TIM, LED_PAUSE_CHANNEL);
            HAL_TIM_PWM_Start(&LED_PWM_TIM, LED_PLAY_CHANNEL);
        }
        else {
            HAL_TIM_PWM_Start(&LED_PWM_TIM, LED_PAUSE_CHANNEL);
            HAL_TIM_PWM_Stop(&LED_PWM_TIM, LED_PLAY_CHANNEL);
        }
        break;
    case BTN_NEXT_Pin:
        push_event(EVENT_NEXT);
        break;
    case BTN_PREV_Pin:
        push_event(EVENT_PREV);
        break;
    default:
        Error_Handler();
        break;
    }
}

void HAL_I2C_MemTxCpltCallback(I2C_HandleTypeDef* hi2c) {
    if (hi2c == &SSD1306_I2C_PORT) {
        ssd1306_dma_busy = false;
    }
}

void HAL_I2C_ErrorCallback(I2C_HandleTypeDef* hi2c) {
    if (hi2c == &SSD1306_I2C_PORT) {
        ssd1306_dma_busy = false;
    }
}

uint8_t* track_path(void) {
    static uint8_t track_path_buffer[] = "audio/000.mp3";

    if (current_track > max_tracks)
        current_track = 1;

    if (current_track < 1)
        current_track = max_tracks;

    // Write digits into the buffer
    track_path_buffer[6] = '0' + (current_track / 100);
    track_path_buffer[7] = '0' + ((current_track / 10) % 10);
    track_path_buffer[8] = '0' + (current_track % 10);

    return track_path_buffer;
}

bool stream_chunk(void) {
    uint8_t buffer[1024] = {};
    UINT bytes_read = 0;

    if (f_read(&file, buffer, sizeof(buffer), &bytes_read) != FR_OK) {
        f_close(&file);
        vs1053_start_new_track();
        current_error = ERROR_DISK;
        change_state(&STATE_ERROR);
        return false;
    }

    if (bytes_read == 0)
        return false;

    vs1053_send_data(buffer, bytes_read);
    return true;
}

uint32_t read_be32(const uint8_t* p) {
    return ((uint32_t)p[0] << 24) | ((uint32_t)p[1] << 16) | ((uint32_t)p[2] << 8) | p[3];
}

bool get_mp3_info(void) {
    uint8_t buf[64];
    UINT br;

    mp3_info.duration = 0;
    mp3_info.title[0] = '\0';

    f_lseek(&file, 0);
    if (f_read(&file, buf, 10, &br) != FR_OK || br != 10)
        return false;

    uint32_t audio_start = 0;

    // parse the ID3 tag
    if (memcmp(buf, "ID3", 3) == 0) {
        const uint8_t version = buf[3];

        // 28‑bit tag size
        const uint32_t tag_size =
            ((uint32_t)buf[6] << 21) |
            ((uint32_t)buf[7] << 14) |
            ((uint32_t)buf[8] << 7) |
            buf[9];

        uint32_t pos = 10;
        const uint32_t end = 10 + tag_size;
        audio_start = end;

        f_lseek(&file, pos);

        // Iterate through ID3 frames
        while (pos + 6 < end) {
            const uint8_t need = (version == 2) ? 6 : 10;
            if (f_read(&file, buf, need, &br) != FR_OK || br != need) break;
            if (buf[0] == 0) break;

            uint32_t size;
            flags.is_title = false;
            flags.is_tlen = false;

            if (version == 2) {
                flags.is_title = (memcmp(buf, "TT2", 3) == 0);
                flags.is_tlen = (memcmp(buf, "TLE", 3) == 0);
                size = ((uint32_t)buf[3] << 16) | ((uint32_t)buf[4] << 8) | buf[5];
            }
            else {
                flags.is_title = (memcmp(buf, "TIT2", 4) == 0);
                flags.is_tlen = (memcmp(buf, "TLEN", 4) == 0);
                size = (version == 4)
                           ? (((uint32_t)buf[4] << 21) | ((uint32_t)buf[5] << 14) | ((uint32_t)buf[6] << 7) | buf[7])
                           : (((uint32_t)buf[4] << 24) | ((uint32_t)buf[5] << 16) | ((uint32_t)buf[6] << 8) | buf[7]);
            }

            if (size == 0 || size > 100000) {
                pos += need;
                f_lseek(&file, pos);
                continue;
            }

            // Extract the title
            if (flags.is_title && mp3_info.title[0] == '\0') {
                const uint32_t r = (size < 64) ? size : 64;
                if (f_read(&file, buf, r, &br) == FR_OK && br == r) {
                    if (buf[0] == 0) {
                        memcpy(mp3_info.title, &buf[1], r - 1);
                        mp3_info.title[r - 1] = '\0';
                    }
                    else if (buf[0] == 1) {
                        uint8_t j = 0;
                        for (uint32_t i = 3; i + 1 < r && j < 63; i += 2) {
                            if (buf[i] == 0) break;
                            mp3_info.title[j++] = buf[i];
                        }
                        mp3_info.title[j] = '\0';
                    }
                }
            }

            // Extract TLEN (duration in ms)
            else if (flags.is_tlen && mp3_info.duration == 0) {
                const uint32_t r = (size < 12) ? size : 12;
                if (f_read(&file, buf, r, &br) == FR_OK && br == r) {
                    uint32_t ms = 0;
                    for (uint8_t i = 0; i < r && buf[i] >= '0' && buf[i] <= '9'; i++)
                        ms = ms * 10 + (buf[i] - '0');
                    mp3_info.duration = ms / 1000;
                }
            }
            pos += need + size;
            f_lseek(&file, pos);

            if (mp3_info.title[0] != '\0' && mp3_info.duration > 0) break;
        }
    }

    // parse the fist MP3 header
    f_lseek(&file, audio_start);
    if (f_read(&file, buf, 4, &br) != FR_OK || br != 4) return true;

    // Validate frame sync
    if ((buf[0] != 0xFF) || (buf[1] & 0xE0) != 0xE0) return true;

    const uint8_t ver = (buf[1] >> 3) & 0x03;
    const uint8_t br_i = (buf[2] >> 4) & 0x0F;
    const uint8_t sr_i = (buf[2] >> 2) & 0x03;

    if (sr_i == 3) return true;

    // Sample rate lookup table
    static const uint16_t sr_table[3][3] = {
        {44100, 48000, 32000},
        {22050, 24000, 16000},
        {11025, 12000, 8000}
    };

    const uint16_t sample_rate = sr_table[ver == 3 ? 0 : ver == 2 ? 1 : 2][sr_i];

    // Side info size depends on MPEG version
    const uint8_t side_info = (ver == 3) ? 32 : 17;

    f_lseek(&file, audio_start + 4 + side_info);
    if (f_read(&file, buf, 8, &br) == FR_OK && br == 8) {
        // Xing / Info VBR header
        if (memcmp(buf, "Xing", 4) == 0 || memcmp(buf, "Info", 4) == 0) {
            if (buf[7] & 0x01) {
                if (f_read(&file, buf, 4, &br) == FR_OK && br == 4) {
                    mp3_info.duration = (read_be32(buf) * 1152UL) / sample_rate;
                }
            }
        }
        // VBRI header
        else if (memcmp(buf, "VBRI", 4) == 0) {
            f_lseek(&file, audio_start + 4 + side_info + 10);
            if (f_read(&file, buf, 4, &br) == FR_OK && br == 4) {
                mp3_info.duration = (read_be32(buf) * 1152UL) / sample_rate;
            }
        }
    }

    // Fallback: estimate duration from file size + bitrate
    if (mp3_info.duration == 0 && br_i > 0 && br_i < 15 && ver == 3) {
        const uint32_t file_size = f_size(&file);
        if (file_size > audio_start) {
            const uint32_t audio_bytes = file_size - audio_start;
            mp3_info.duration = (audio_bytes / 125) / mpeg1_bitrates[br_i];
        }
    }

    return true;
}

void open_file(void) {
    const uint8_t* path = track_path();

    // Try opening current track
    if (f_open(&file, (const TCHAR*)path, FA_READ) != FR_OK) {
        // Wrap to track 1
        current_track = 1;
        path = track_path();

        if (f_open(&file, (const TCHAR*)path, FA_READ) != FR_OK) {
            f_close(&file);
            vs1053_start_new_track();
            current_error = ERROR_DISK;
            change_state(&STATE_ERROR);
        }
    }

    if (!get_mp3_info()) {
        strncpy(mp3_info.title, "UNKNOWN", sizeof(mp3_info.title) - 1);
        mp3_info.title[sizeof(mp3_info.title) - 1] = '\0';
        mp3_info.duration = 0;
    }
}

void playback_init(void) {
    __HAL_TIM_SET_PRESCALER(&LED_PWM_TIM, LED_PWM_FAST);
    HAL_TIM_PWM_Start(&LED_PWM_TIM, LED_PAUSE_CHANNEL);
    HAL_TIM_PWM_Stop(&LED_PWM_TIM, LED_PLAY_CHANNEL);

    DIR dir;
    FILINFO fno;

    max_tracks = 0;

    FRESULT res = f_opendir(&dir, "audio");
    if (res == FR_OK) {
        for (;;) {
            res = f_readdir(&dir, &fno); // Read a directory item
            if (res != FR_OK || fno.fname[0] == 0) break;

            if (!(fno.fattrib & (AM_DIR | AM_HID | AM_SYS))) {
                ++max_tracks;
            }
        }
        f_closedir(&dir); // Close the directory
    }

    open_file();
}

void playback_run(const Event_t event) {
    switch (event) {
    case EVENT_NEXT:
        f_close(&file);
        vs1053_start_new_track();

        ++current_track;
        open_file();
        break;
    case EVENT_PREV:
        f_close(&file);
        vs1053_start_new_track();

        --current_track;
        open_file();
        break;
    case EVENT_NONE:
    default:
        break;
    }

    display_update(DISPLAY_MODE_PLAYBACK);

    if (!flags.is_playing)
        return;

    // play the file
    if (!stream_chunk()) {
        HAL_Delay(DISPLAY_UPDATE_MS);
        display_update(DISPLAY_MODE_PLAYBACK);
        HAL_Delay(1000);
        // End of file reached → go to next track
        f_close(&file);
        vs1053_start_new_track();

        ++current_track;
        open_file();
    }
}

void error_init(void) {
    f_close(&file);
    flags.is_playing = false;

    __HAL_TIM_SET_PRESCALER(&LED_PWM_TIM, LED_PWM_SLOW);
    HAL_TIM_PWM_Start(&LED_PWM_TIM, LED_PAUSE_CHANNEL);
    HAL_TIM_PWM_Stop(&LED_PWM_TIM, LED_PLAY_CHANNEL);
}

void error_run(const Event_t event) {
    (void)event;

    static uint32_t last_check = 0;
    static bool started = false;

    display_update(DISPLAY_MODE_ERROR);

    const uint32_t now = HAL_GetTick();

    switch (current_error) {
    case ERROR_NONE:
        change_state(&STATE_PLAYBACK);
        break;

    case ERROR_DISK:
        if (now - last_check >= SD_CHECK_INTERVAL) {
            last_check = now;

            if (sdcard_recover()) {
                current_error = ERROR_NONE;
                change_state(&STATE_PLAYBACK);
            }
        }
        break;

    case ERROR_RESET:
        if (!started) {
            HAL_TIM_PWM_Start(&LED_PWM_TIM, LED_PLAY_CHANNEL);
            started = true;
        }
        break;

    default:
        Error_Handler();
        break;
    }
}

void display_init(void) {
    ssd1306_Init();
    ssd1306_Fill(Black);
    ssd1306_SetCursor(0, 0);
    ssd1306_UpdateScreen();
}

void display_update(const DisplayMode_t mode) {
    const uint32_t current_time = HAL_GetTick();
    static uint32_t last_update = 0;

    if (last_update != 0 && (current_time - last_update) < DISPLAY_UPDATE_MS)
        return;

    last_update = current_time;

    const uint16_t current_sec = vs1053_get_current_decode_time();

    // max chars at a font size of 7x10 + '/0'
    char buffer[19];

    static const char* const title_msg[] = {
        [DISPLAY_MODE_PLAYBACK] = "PLAYBACK >>",
        [DISPLAY_MODE_ERROR] = "|  ERROR  |"
    };

    static const char* const error_msg[] = {
        [ERROR_DISK] = "Reinsert the card",
        [ERROR_RESET] = "Reset the device",
    };

    ssd1306_Fill(Black);
    ssd1306_SetCursor(0, 0);
    ssd1306_WriteString((char*)title_msg[mode], Font_7x10, White);

    switch (mode) {
    case DISPLAY_MODE_PLAYBACK:
        ssd1306_SetCursor(84, 0);
        ssd1306_WriteString(flags.is_playing ? "PLAY" : "PAUSE", Font_7x10, White);

        // Volume
        buffer[0] = 'V';
        buffer[1] = 'o';
        buffer[2] = 'l';
        buffer[3] = 'u';
        buffer[4] = 'm';
        buffer[5] = 'e';
        buffer[6] = ':';
        buffer[7] = ' ';

        if (volume == 100) {
            buffer[8] = '1';
            buffer[9] = '0';
            buffer[10] = '0';
            buffer[11] = '%';
            buffer[12] = '\0';
        }
        else {
            buffer[8] = (volume / 10) + '0';
            buffer[9] = (volume % 10) + '0';
            buffer[10] = '%';
            buffer[11] = '\0';
        }

        ssd1306_SetCursor(0, 12);
        ssd1306_WriteString(buffer, Font_7x10, White);

        // Scrolling title
        ssd1306_SetCursor(0, 24);
        const uint8_t len = strlen(mp3_info.title);
        const uint8_t win = 18;

        static uint8_t paused = 1;
        static uint8_t tick = 0;
        static uint8_t off = 0;

        static uint16_t last_track = 0;
        if (last_track != current_track) {
            last_track = current_track;
            off = 0;
            tick = 0;
            paused = 1;
        }

        if (len > win) {
            if (off == 0 && paused) {
                if (++tick >= 8) {
                    tick = 0;
                    paused = 0;
                }
            }
            else {
                if (++tick >= 2) {
                    tick = 0;
                    if (++off > len - win) {
                        off = 0;
                        paused = 1;
                        tick = 0;
                    }
                }
            }

            memcpy(buffer, &mp3_info.title[off], win);
            buffer[win] = 0;
            ssd1306_WriteString(buffer, Font_7x10, White);
        }
        else {
            ssd1306_WriteString(mp3_info.title, Font_7x10, White);
        }

        // Current time
        uint16_t hours = current_sec / 3600;
        uint8_t minutes = (current_sec % 3600) / 60;
        uint8_t seconds = current_sec % 60;

        buffer[0] = (hours / 10) + '0';
        buffer[1] = (hours % 10) + '0';
        buffer[2] = ':';
        buffer[3] = (minutes / 10) + '0';
        buffer[4] = (minutes % 10) + '0';
        buffer[5] = ':';
        buffer[6] = (seconds / 10) + '0';
        buffer[7] = (seconds % 10) + '0';
        buffer[8] = '\0';

        ssd1306_SetCursor(0, 36);
        ssd1306_WriteString(buffer, Font_7x10, White);

        // Duration
        hours = mp3_info.duration / 3600;
        minutes = (mp3_info.duration % 3600) / 60;
        seconds = mp3_info.duration % 60;

        buffer[0] = (hours / 10) + '0';
        buffer[1] = (hours % 10) + '0';
        buffer[2] = ':';
        buffer[3] = (minutes / 10) + '0';
        buffer[4] = (minutes % 10) + '0';
        buffer[5] = ':';
        buffer[6] = (seconds / 10) + '0';
        buffer[7] = (seconds % 10) + '0';
        buffer[8] = '\0';

        ssd1306_SetCursor(0, 48);
        ssd1306_WriteString(buffer, Font_7x10, White);
        break;

    case DISPLAY_MODE_ERROR:
        ssd1306_SetCursor(0, 22);
        ssd1306_WriteString((char*)error_msg[current_error], Font_7x10, White);
        break;
    default:
        Error_Handler();
        break;
    }

    ssd1306_UpdateScreen();
}

void encoder_init(Encoder_t* enc, TIM_HandleTypeDef* htim) {
    enc->htim = htim;
    enc->last_counter = (int32_t)__HAL_TIM_GET_COUNTER(htim);
    enc->accum = 0;
    HAL_TIM_Encoder_Start(htim, TIM_CHANNEL_ALL);
}

void encoder_poll(Encoder_t* enc) {
    const int32_t current_counter = (int32_t)__HAL_TIM_GET_COUNTER(enc->htim);
    const int32_t delta = current_counter - enc->last_counter;
    enc->last_counter = current_counter;
    enc->accum += delta;
    const int8_t detents = (int8_t)(enc->accum / COUNTS_PER_DETENT);
    enc->accum -= detents * COUNTS_PER_DETENT;
    enc->steps = detents;
}

bool sdcard_init(void) {
    if (disk_initialize(0) == 0 && f_mount(&fatfs, "", 1) == FR_OK) {
        return true;
    }
    return false;
}

bool sdcard_recover(void) {
    // set all the spi pins to high
    HAL_GPIO_WritePin(X_CS_GPIO_Port, X_CS_Pin, GPIO_PIN_SET);
    HAL_GPIO_WritePin(XD_CS_GPIO_Port, XD_CS_Pin, GPIO_PIN_SET);
    HAL_GPIO_WritePin(SD_CS_GPIO_Port, SD_CS_Pin, GPIO_PIN_SET);
    HAL_Delay(100);

    // unmount and reset the drive state
    f_mount(NULL, "", 0);
    extern Disk_drvTypeDef disk;
    disk.is_initialized[0] = 0;

    if (disk_initialize(0) != 0) return false;
    if (f_mount(&fatfs, "", 1) != FR_OK) return false;

    return true;
}

void change_state(const State_t* new_state) {
    if (current_state != new_state) {
        current_state = new_state;
        if (current_state->init) {
            current_state->init();
        }
    }
}
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

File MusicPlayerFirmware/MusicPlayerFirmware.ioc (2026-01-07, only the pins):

Mcu.UserName=STM32G031K8Tx
PA0.GPIO_Label=ENC_A
PA0.Signal=S_TIM2_CH1_ETR
PA1.GPIO_Label=ENC_B
PA1.Signal=S_TIM2_CH2
PA10.Signal=I2C1_SDA
PA13.GPIO_Label=T_JTMS
PA13.Signal=SYS_SWDIO
PA14-BOOT0.GPIO_Label=T_JTCK
PA14-BOOT0.Signal=SYS_SWCLK
PA4.GPIO_Label=SD_CS
PA4.Signal=GPIO_Output
PA5.GPIO_Label=SPI1_SCK
PA5.Signal=SPI1_SCK
PA6.GPIO_Label=SPI1_MISO
PA6.Signal=SPI1_MISO
PA7.GPIO_Label=SPI1_MOSI
PA7.Signal=SPI1_MOSI
PA9.Signal=I2C1_SCL
PB0.GPIO_Label=BTN_PLAYPAUSE
PB0.Signal=GPXTI0
PB3.GPIO_Label=DREQ
PB3.Signal=GPIO_Input
PB4.GPIO_Label=LED_PAUSE
PB4.Signal=S_TIM3_CH1
PB5.GPIO_Label=LED_PLAY
PB5.Signal=S_TIM3_CH2
PB8.GPIO_Label=BTN_NEXT
PB8.Signal=GPXTI8
PB9.GPIO_Label=BTN_PREV
PB9.Signal=GPXTI9
PC6.GPIO_Label=LD3 [Green]
PC6.Signal=GPIO_Output

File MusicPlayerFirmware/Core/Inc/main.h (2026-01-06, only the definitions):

#define BTN_PREV_Pin GPIO_PIN_9
#define BTN_PREV_GPIO_Port GPIOB
#define BTN_PREV_EXTI_IRQn EXTI4_15_IRQn
#define T_NRST_Pin GPIO_PIN_2
#define T_NRST_GPIO_Port GPIOF
#define T_NRST_EXTI_IRQn EXTI2_3_IRQn
#define ENC_A_Pin GPIO_PIN_0
#define ENC_A_GPIO_Port GPIOA
#define ENC_B_Pin GPIO_PIN_1
#define ENC_B_GPIO_Port GPIOA
#define SD_CS_Pin GPIO_PIN_4
#define SD_CS_GPIO_Port GPIOA
#define SPI1_SCK_Pin GPIO_PIN_5
#define SPI1_SCK_GPIO_Port GPIOA
#define SPI1_MISO_Pin GPIO_PIN_6
#define SPI1_MISO_GPIO_Port GPIOA
#define SPI1_MOSI_Pin GPIO_PIN_7
#define SPI1_MOSI_GPIO_Port GPIOA
#define BTN_PLAYPAUSE_Pin GPIO_PIN_0
#define BTN_PLAYPAUSE_GPIO_Port GPIOB
#define BTN_PLAYPAUSE_EXTI_IRQn EXTI0_1_IRQn
#define LD3_Pin GPIO_PIN_6
#define LD3_GPIO_Port GPIOC
#define X_CS_Pin GPIO_PIN_11
#define X_CS_GPIO_Port GPIOA
#define XD_CS_Pin GPIO_PIN_12
#define XD_CS_GPIO_Port GPIOA
#define T_JTMS_Pin GPIO_PIN_13
#define T_JTMS_GPIO_Port GPIOA
#define T_JTCK_Pin GPIO_PIN_14
#define T_JTCK_GPIO_Port GPIOA
#define DREQ_Pin GPIO_PIN_3
#define DREQ_GPIO_Port GPIOB
#define LED_PAUSE_Pin GPIO_PIN_4
#define LED_PAUSE_GPIO_Port GPIOB
#define LED_PLAY_Pin GPIO_PIN_5
#define LED_PLAY_GPIO_Port GPIOB
#define BTN_NEXT_Pin GPIO_PIN_8
#define BTN_NEXT_GPIO_Port GPIOB
#define BTN_NEXT_EXTI_IRQn EXTI4_15_IRQn
#define EVENT_QUEUE_SIZE 8
#define SD_SPI_HANDLE hspi1
#define SPI_HANDLE hspi1

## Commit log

2026-01-05 Refactor button naming and add event/state system
    Renamed BTN_PLAY to BTN_PLAYPAUSE throughout the codebase for clarity. Introduced an event queue and state machine structure in main.c to handle playback and error states, including encoder and display initialization. Updated CMakeLists.txt to add SSD1306 display and user_diskio_spi sources. Modified user_diskio.c to delegate disk operations to SPI-specific functions. Minor copyright year corrections.
    [MusicPlayerFirmware.ioc, main.c, main.h]
2026-01-05 Revise README for improved clarity and structure
    Updated README.md to enhance clarity and structure, including hardware components, features, pin configuration, software architecture, development phases, and building instructions.
2026-01-05 Add SD card error handling and update FatFs config
    Introduced error state management and display updates for SD card errors in main.c. Added SD card initialization and recovery logic. Updated ffconf.h to disable mkfs, fast seek, and long file name support, changed code page, and adjusted file lock settings. Removed unused FatFs code page conversion file (ccsbcs.c) and updated project configuration files accordingly.
    [MusicPlayerFirmware.ioc, main.c]
2026-01-05 Add VS1053 audio codec driver and integrate with firmware
    Added VS1053 driver source and header files for audio codec support. Updated CMakeLists.txt to include the new component. Defined VS1053_WAIT_FOR_DREQ macro and integrated it into main.c for proper D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
2026-01-05 Refactor VS1053 interface and improve volume handling
    Replaced MP3_CS with X_CS throughout the codebase for consistency. Improved VS1053 volume control with a logarithmic table and interpolation, added track start/flush logic, and updated SPI prescaler usage for data transfer. Enhanced error handling and display messaging for device and SD card errors.
    [MusicPlayerFirmware.ioc, main.c, main.h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]
2026-01-05 Refactor VS1053 data send and flush logic
    Simplified vs1053_send_data to send fixed 32-byte chunks and refactored SPI speed handling. Removed unused SPI prescaler defines and play/pause functions, adjusted volume initialization, and updated flush logic for improved buffer management. Removed pauses and play functions.
    [vs1053.c]
2026-01-06 Refactor VS1053 driver and add playback features
    Updated VS1053 driver to use a configurable SPI handle, improved SPI speed switching, and refactored volume control to use a lookup table. Added playback logic to main.c for track selection, volume adjustment, and streaming audio data in chunks. Enhanced display to show volume and playback time. Fixed SPI speed settings for SD card access.
    [main.c, main.h, vs1053.c]
2026-01-06 Increase FATFS minimization level and refactor main.c
    Raised _FS_MINIMIZE from 1 to 2 in FATFS configuration to further reduce unused API functions. Refactored main.c for improved code style and readability, updated open_file logic for better error handling, and removed unused parse_id3 declaration. Also removed VS1053_MODE_SM_LAYER12 from vs1053_soft_reset.
    [MusicPlayerFirmware.ioc, main.c, vs1053.c]
2026-01-06 Improve track handling and update FATFS config
    Track navigation now wraps based on the actual number of tracks in the audio directory, determined at initialization. The decode time function's return type was corrected to uint16_t. FATFS configuration was updated to use code page 850 and minimization level 1 for improved compatibility.
    [MusicPlayerFirmware.ioc, main.c, vs1053.c]
2026-01-07 Add MP3 ID3 title parsing and display scrolling
    Introduces MP3Info_t to store track title and duration, adds get_mp3_info() to parse ID3 tags for the title, and updates display_update() to show and scroll long titles on the OLED. Also refactors de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
2026-01-07 Revise README for clarity and additional details
    Updated README with changes to DMA channels, ID3 tag extraction, file naming, and added images.
2026-01-28 Add initial Music Player PCB design files
    Added KiCad project files for the Music Player, including schematic, PCB layout, project settings, and backup archives. This is the initial commit for the hardware design.
    [MusicPlayer.kicad_pcb, MusicPlayer.kicad_sch]
2026-01-28 Add Music Maker FeatherWing symbol and update schematic
    Replaced a capacitor symbol with a new custom symbol for the Adafruit Music Maker FeatherWing in the schematic, including pin definitions and properties. Updated the project and symbol cache files accordingly. Also rotated backup files, removing old ones and adding new backups.
    [MusicPlayer.kicad_sch]
2026-01-29 Add input, output, power, and USB schematics
    Added new KiCad schematic files for Inputs, Outputs, Power, and USB. Updated MusicPlayer PCB and schematic files, replaced old backup files with new ones, and added a new untitled schematic. These changes expand the project with additional schematic modules and update the main board design.
    [Inputs.kicad_sch, Outputs.kicad_sch, Power.kicad_sch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]
2026-01-29 Restarted the schematic
    It was getting way to full.
    [Inputs.kicad_sch, MCU.kicad_sch, Outputs.kicad_sch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]
2026-01-29 Add power supply symbols to Power schematic
    Added standard library symbols for connectors, capacitors, Schottky diodes, inductors, resistors, linear and switching regulators, and power rails (+3V3, +5V, +BATT, GND, VBUS) to Power.kicad_sch. Al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
    [Power.kicad_sch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]
2026-01-30 Update Power schematic with new symbols and components
    Replaced and added several symbols in Power.kicad_sch, including MCP73831-2-OT battery charger, TPS61090 boost converter, and updated passive components (LED, capacitor, inductor, resistor). Adjusted symbol properties, footprints, and pinouts to match new components. Updated schematic text, junctions, and added descriptive notes for charge rate and low battery voltage. Minor tweaks to MusicPlayer.kicad_sch sheet positions and grouping in MusicPlayer.kicad_pro.
    [Power.kicad_sch, USB.kicad_sch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]
2026-01-31 Add components & update KiCad schematic settings
    Add and refine schematic symbols and project settings across PCB files. Inputs.kicad_sch: expand library symbols and instances (resistor, SPDT switch, power flags, GND, wiring and global labels). Power.kicad_sch: add a Schottky diode symbol, replace/regenerate regulator symbol (rename to LD1117S33TR_SOT223 and update datasheet/description/keywords), and add simulation transistor symbols (NMOS, PNP) with Sim.* properties and updated graphics. MusicPlayer.kicad_pro: tighten lib_symbol_mismatch to error, adjust BOM settings (exclude_dnp true, show quantity, hide DNP/Exclude fields, add/hide Sim.Device/Sim.Type fields) and change BOM sorting to Re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
    [Inputs.kicad_sch, Power.kicad_sch, USB.kicad_sch]
2026-01-31 Finished the schematic.
    [Inputs.kicad_sch, MCU.kicad_sch, Outputs.kicad_sch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]
2026-02-01 Finale touch up on schematics
    Added net classes and did set the pcb configuration values.
    [Power.kicad_sch, USB.kicad_sch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]
2026-02-01 fixed schematic errors
    Accidentally set all SMD 0603 to SMD 0603 metric
    [Inputs.kicad_sch, MCU.kicad_sch, Outputs.kicad_sch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]
2026-02-02 Finished PCB parts layout
    [MusicPlayer.kicad_pcb]
2026-02-02 Finished initial pcb routing
    [MCU.kicad_sch, Power.kicad_sch, USB.kicad_sch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]
2026-02-03 Finished making a PCB for it
    [MCU.kicad_sch, Outputs.kicad_sch, Power.kicad_sch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]

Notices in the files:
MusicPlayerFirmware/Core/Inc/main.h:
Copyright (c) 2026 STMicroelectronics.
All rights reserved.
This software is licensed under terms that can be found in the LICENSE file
